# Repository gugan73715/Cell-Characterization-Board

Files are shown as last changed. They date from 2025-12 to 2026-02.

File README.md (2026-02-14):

# Cell Characterization Board V1.2
This project is a 10-channel sequential lithium-ion cell (18650) characterization instrument designed to measure cell voltage, discharge current, internal resistance, and capacity under a controlled constant-current load of up to 5 A. The Cell data would be displayed on an LCD and stored on a MicroSD card which can be used to plot discharge curves using Excel/Matlab/Python. Protection features include Reverse Polarity Protection for each channel, Low voltage cut-off and hardware controlled sequential switching circuit with hardware interlock to create mutually exclusive channels.

V1.2 serves as a validation vehicle for the custom analog front-end and discharge bus, utilizing a modular MCU architecture (Nucleo/Nano) to minimize BOM and assembly costs as well as accelerate testing. Planned V2 would be an integrated STM32G0B1CCT6 based revision with a SPI TFT display.

## Primary Use Case

This system is designed to characterize and screen individual lithium-ion cells prior to adding it into a battery pack for UBC Rocket's Cloudburst rocket. This allows to exclude defective, mismatched, or degraded cells before battery pack assembly. It also helps prevent cell imbalance in series strings, individual cells overheating during discharge and reduced pack capacity due to lower cell capacity. This device could also be used in other projects involving high-energy battery systems such as Student Formula SAE electric vehicles, solar car teams, and any project requiring testing and characterization of large numbers of lithium-ion cells prior to pack assembly. 

## Key design goals
- Programmable constant-current discharge
- Accurate, ratiometric voltage and current measurement
- Fault-tolerant handling of reverse polarity and missing cells
- Sequential testing to minimize BOM cost and thermal complexity
- Hardware based protection features for reliability
- Reduce manufacturing and assembly cost as much as possible due to budget constraint
- Rapid bring up
- Clear documentation of design intent and constraints
  
# PCB Design:
## Latest 3D Render:
Cell Characterization Board V1 2 3D Render - Top
Cell Characterization Board V1 2 3D Render - Bottom
## V1.2:


## System Validation & Discharge Data:
CELL ID 3
Full discharge curve of a Sony VTC4 cell generated using the cell data from V1.2 10-channel tester, ploted using MATLAB. The system maintained a stable 1.5A constant current discharge, yielding a capacity measurement that matched the manufacturer's datasheet within 5% and a DCIR of 33mohm. This data confirms the precision of the op-amp control loop over a full discharge cycle and MOSFET maintained a approximate 45-50C temperature.

## Overview:
The system is implemented on a custom 4-layer mixed-signal PCB (SIG / GND / PWR / SIG) optimized for high-current power handling, precision analog measurement and noise handling. GND and PWR plane are continuous and unbroken providing low-impedance return paths and a stable reference plane. Proper zoning (Analog/Digital/Power) based component placement for noise immunity and short traces. Cell holders and relays are placed on both sides to decrease PCB size which helps reduce PCB manufacturing cost.
### High-Current Routing
- All >2 A paths use wide copper pours with stitching vias if possible to distribute the current
- All high current paths are kept as far away as possible from sensitive analog traces

### Analog Integrity
- All analog traces are on top layer with a GND plane below them
- Analog traces are kept as short as possible
- Important analog signals are buffered and have a decoupling capacitor close to it
- Quasi-Kelvin sense (Separate PWR and SIG traces but shared GND) is used for current and voltage measurement
  
### Noise and Protection
- Relay drive and switching currents are physically separated from the analog front-end
- External flyback diodes placed adjacent to each relay
- Relay coil and Flyback traces are kept as short as possible and fanned out to prevent noise from adjacent traces
- Decoupling capacitors placed close to each IC supply pin
- Reverse polarity protection for each channel using P-channel MOSFETs
- V_Cell traces are connected straight to cell holder for Quasi-kelvin sense and current limiting resistor on each trace to protect the MUX in case of reverse polarity.
- NTC on Load MOSFET's heatsink for active over temperature protection
- 30 ms Soft start for BUCK IC to prevent overshoot and inrush current

### Debugging
- Testpoints for 5V, 3.3V, 2.5V ref, GND, I_set, Constant Current op-amp feedback line, MOSFET Gate and I_sense.
- External UART, SPI and I2C headers for logic analysis
- MUX-out(Cell voltage) is accessible through MCU header

### Assembly & Cost Optimization
- 5 channels were placed on top and bottom to reduce PCB size and save fabrication costs
- Passive components are assembled by fabrication house and all of them have been placed on top for one sided assembly
- Active ICs, cell holders and connectors are hand-assembled post-fabrication to reduce assembly cost while retaining full control over critical components

# Hardware
08e247f1-ca4d-435c-84c2-786f73447f0c-0

## System Architecture Summary (Click subsection header for schematic sheet)
<details>
<summary><h3>Buck and LDO</h3></summary>
  
Buck and LDO Schematic (https://github.com/user-attachments/assets/7cbbd1c2-d676-4704-b09d-97c5c336276e)
</details>

- input DC Jack / XT60: 8–40 V
- input USB-C: 5V 3A (Non-PD)
- 5 V logic rail via AP64502QSP-13 based synchronous buck converter
- Dedicated 3.3 V LDO for MicroSD and SPI

<details>
<summary><h3>Constant Current Sink</h3></summary>
  
Constant Current Sink (https://github.com/user-attachments/assets/1adb6a28-354b-4ce8-b8a3-19815ae03084)
</details>

- IRLZ44N Logic level MOSFET and TLV9162 control op-amp
- Low side 50mohm 3W shunt
- DAC60501ZDGSR 12-bit DAC for precise control of discharge current and controlled via I2C
- Internal 2.5 V precision reference of DAC is shared by ADC as well
- Amplified I_sense signal (0 - 2.5V) using MCP6001 for better resolution
- Theoretical MOSFET temperature with heat sink (θ_normal = 2.6 C/W) at max case (5A) is 115.86 C (Assuming 25 C ambient)
- Load MOSFET temperature monitoring via NTC
- Maximum discharge current: 5 A

<details>
<summary><h3>MCU</h3></summary>

MCU (https://github.com/user-attachments/assets/76e0b13c-49a7-4943-83e6-0d6fc5a95909)

</details>

- Compatible with 3.3V STM32 Nucleo boards with nano connectivity like NUCLEO-L432KC and Arduino nano
- External I2C header for debugging and future expansion modules
- External UART header for telemetry

<details>
<summary><h3>Cell Holder</h3></summary>

Cell Holder (https://github.com/user-attachments/assets/d6683df6-3a02-4f7b-97c8-28835414f6b9)

</details>

- DIY 3D printed SMD 18650 cell holders (similar to Keystone 1043) with 0.2mm nickel strips as cell contacts to save BOM cost
- Reverse polarity protection for each channel using MCQ7328-TP P-channel MOSFETs
- Cell voltage sense traces are connected straight to cell holder pads for quasi-kelvin sense

<details>
<summary><h3>Sequential Cell Switching</h3></summary>

Sequential Cell Switching (https://github.com/user-attachments/assets/236b81a5-ea0e-4242-863e-f045defb3f62)

</details>

- Control Logic: MCU -> I2C Expander -> Line Decoder (For mutually exclusive channels) -> Relay Driver -> Relay -> Cell Holder
- Relay-based physical isolation of cells driven by darlington transistor array on low side
- PCF8575PWR I2C expander for I/O expansion
- CD4514BM96 decoder to prevent connecting more than one channel at the same time and an active high inhibit pin controlled by I2C expander
- External pull ups on all I2C lines and external flyback diodes on all relays

<details>
<summary><h3>Cell Monitoring</h3></summary>

Cell Monitoring (https://github.com/user-attachments/assets/edf4d94d-06c7-463c-b50f-4eb45057faaf)

</details>

- CD74HC4067SM96 16:1 analog MUX for cell voltage sampling
- MUX out is converted to a signal of 0 to 2.5V using a voltage divider and then buffered
- Current limiting resistor(limits to 2.1mA) on each channel to protect the MUX in case of reverse polarity (MUX's internal ESD clamp diode forward biases)

<details>
<summary><h3>MicroSD</h3></summary>

MicroSD (https://github.com/user-attachments/assets/2866bfb3-0861-4d20-aa4e-4b10ece4d7fd)

</details>

- Data is written to MicroSD using SPI
- TXU0304PWR unidirectional voltage level translator for 5V to 3.3V for SCK, MOSI, CS (MCU to MicroSD) and 3.3V to 5V for MISO (MicroSD to MCU)
- SD detect LED for user-friendliness
- Parameters: Time, Cell Voltage, Discharge Current, Internal Resistance, I_set, Cut-off voltage and capacity (mAh / Wh)
- Internal Resistance is calculated using r = (V_OC - V_sense)/I. (Voltage drop across cell under a load)

## Prototyping and Validation:

### LTspice simulation: (Constant Current Sink)



### Breadboard prototyping:


- Constant current sink prototype built using IRL510 + LM158J
- Shunt resistor: 1.5 Ω / 5 W
- Gate and feedback resistors as implemented in hardware
- 0.5V out DAC emulated via resistive divider from 5 V
- Load driven by a current-limited (For safety) bench supply (2.5 V–4.2 V sweep)

Measured discharge current remained approximately constant (~340 mA) across the full input voltage range.

# Firmware

- Initial firmware developed using Arduino IDE for rapid bring-up
- Secondary firmware under development using STM32CubeIDE with STM32HAL and testing using an NUCLEO-G431KB

### Objectives:

- Validation of the sequential switching mechanism to guarantee mutual exclusivity of active channels
- Cell voltage sampling verification across all channels using the MUX
- Verify ADC and DAC resolution using the shared 2.5 V reference
- Validation of current measurement accuracy and stability across the full discharge range

# Planned Revision (V2):

- Transitioning to a STM32G0B1CCT6 onboard MCU
- Switching to SPI-based TFT display for real-time visualization
- Switching to Zero-drift, ultra-low-offset op-amp for better accuracy
- NTC on each channel for cell temperature monitoring
- Short-circuit and overtemperature protection for each channel 
- Firmware detection of protection features and informing the user
- Audible and visual fault and status indication (buzzer and status LEDs)

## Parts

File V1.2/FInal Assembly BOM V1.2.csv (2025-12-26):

Description | Designator | Footprint | JLCPCB Part #
Chip Capacitor, 100 nF, +/- 10%, 50 V, 0805 (2012 Metric) | C1, C2, C3, C4, C12, C14, C15, C16, C17, C18, C19, C20, C23, C24, C25 | CAPC2013X95X50LL10T25 | C28233
Chip Multilayer Ceramic Capacitors for General Purpose, 1206, 47uF, X5R, 15%, 20%, 10V | C5, C6, C7, C8, C9 | FP-GRM31C-0_2-e0_3_0_8-IPC_C | C76659
CAP CER 10UF 50V X5R 1206 | C10, C11 | FP-CL31-IPC_C | C1710
Ceramic Capacitor for Automotive 10nF ±10% 100VDC X8R 0805 Paper T/R | C13 | FP-GCM219-0_15-IPC_C | C1848
Chip Capacitor, 1 uF, +/- 10%, 25 V, -55 to 125 degC, 1206 (3216 Metric), RoHS, Tape and Reel | C21, C22 | CAPC3216X180X50ML20T25 | C1848
Surface Mount Glass Passivated Rectifier, 1000V, 1 A, -65 to 125 degC, 2-Pin SMA Package, RoHS, Tape and Reel | D1, D2, D3, D4, D5, D6, D7, D8, D9, D10 | DIOD-S1M-13-F-SMA-2_V | C95872
LED Yellow, 75 mW, 80 mA, -55 to 85 degC, 2-Pin SMD, RoHS, Tape and Reel | D11 | LTST-C170KSKT_V | C2296
Chip Ferrite Bead Array, 1206, 120O @ 100MHz, 0.02O, 25%, 3.5A | FB1 | FP-BLM31-0_2-t1_1-MFG | C85841
Chip Resistor, 10 KOhm, +/- 1%, 125 mW, -55 to 155 degC, 0805 (2012 Metric) | R1, R11 | RESC2013X50X35ML15T15 | C17414
1.5kO ±5% 0.125W 0805 Thick Film Chip Resistor AEC-Q200 compliant | R2 | FP-RMCF0805-IPC_B | C4310
RES SMD 100 OHM 1% 1/8W 0603 | R3, R4 | FP-MCT0603-IPC_B | C23186
Chip Resistor, 4.7 KOhm, +/- 1%, 0.125 W, -55 to 155 degC, 0805 (2012 Metric) | R5, R8, R21, RPU1, RPU2, RPU3, RPU4, RPU5, RPU6, RPU7, RPU8 | RESC2013X70X40ML20T20 | C17673
RES 1.05K OHM 0.5% 1/5W 0805 | R6 | FP-MCU0805-IPC_C | C17695
220O ±5% 0.125W 0805 Thick Film Chip Resistor AEC-Q200 compliant | R7 | FP-RMCF0805-IPC_A | C17557
8K2 0.125W 1% 0805 (2012 Metric) SMD | R9 | RESC0805(2012)_N | C17828
RES Thick Film, 7.5kO, 1%, 0.5W, 100ppm/°C, 0805 | R10 | FP-CRCW0805-HPe3-IPC_B | C17807
RES 10kO 5.00% 0.2W 0603 | R12, R22, R23, R24, R25, R26, R27, R28, R29, R30, R31 | FP-AC0603-IPC_A | C25804
Thick Film Chip Resistors 0805 300O 0.125W 1% 100ppm/°C | R13, R19 | FP-CR0805-MFG | C17617
CRGP0805 18KO 0.33W ±100ppm/°C 1% 150V | R14, R16 | FP-CRGP0805-IPC_C | C17506
1kO ±0.1% 0.125W, 1/8W Chip Resistor 0805 (2012 Metric) Moisture Resistant Thin Film | R15 | FP-RN73R2A-IPC_A | C17513
RES 1.05K OHM 0.5% 1/5W 0805 | R17, R18 | FP-MCU0805-IPC_A | C17604
RES Thick Film, 200kO, 1%, 0.33W, 100ppm/°C, 0603 | R20 | FP-CRCW0603-HPe3-MFG | C17617
RES Thin Film, 2kO, 0.1%, 0.1W, 25ppm/°C, 0603 | R32, R33, R34, R35, R36, R37, R38, R39, R40, R41 | FP-TFCR0603-IPC_B | C22975
CRGCQ 0603 1K2 1% | R42 | FP-CRGCQ0603-IPC_C | C22765
CRGCQ 0603 2K2 1% | R43 | FP-CRGCQ0603-IPC_C | C4190
RES 0.05 OHM 1% 3W 2512 | SHUNT | FP-CRA2512-IPC_A | C160588
SWITCH TACTILE SPST-NO 0.05A 24V | START_SW, STOP_SW | FP-2-1977223-2-MFG | C963361

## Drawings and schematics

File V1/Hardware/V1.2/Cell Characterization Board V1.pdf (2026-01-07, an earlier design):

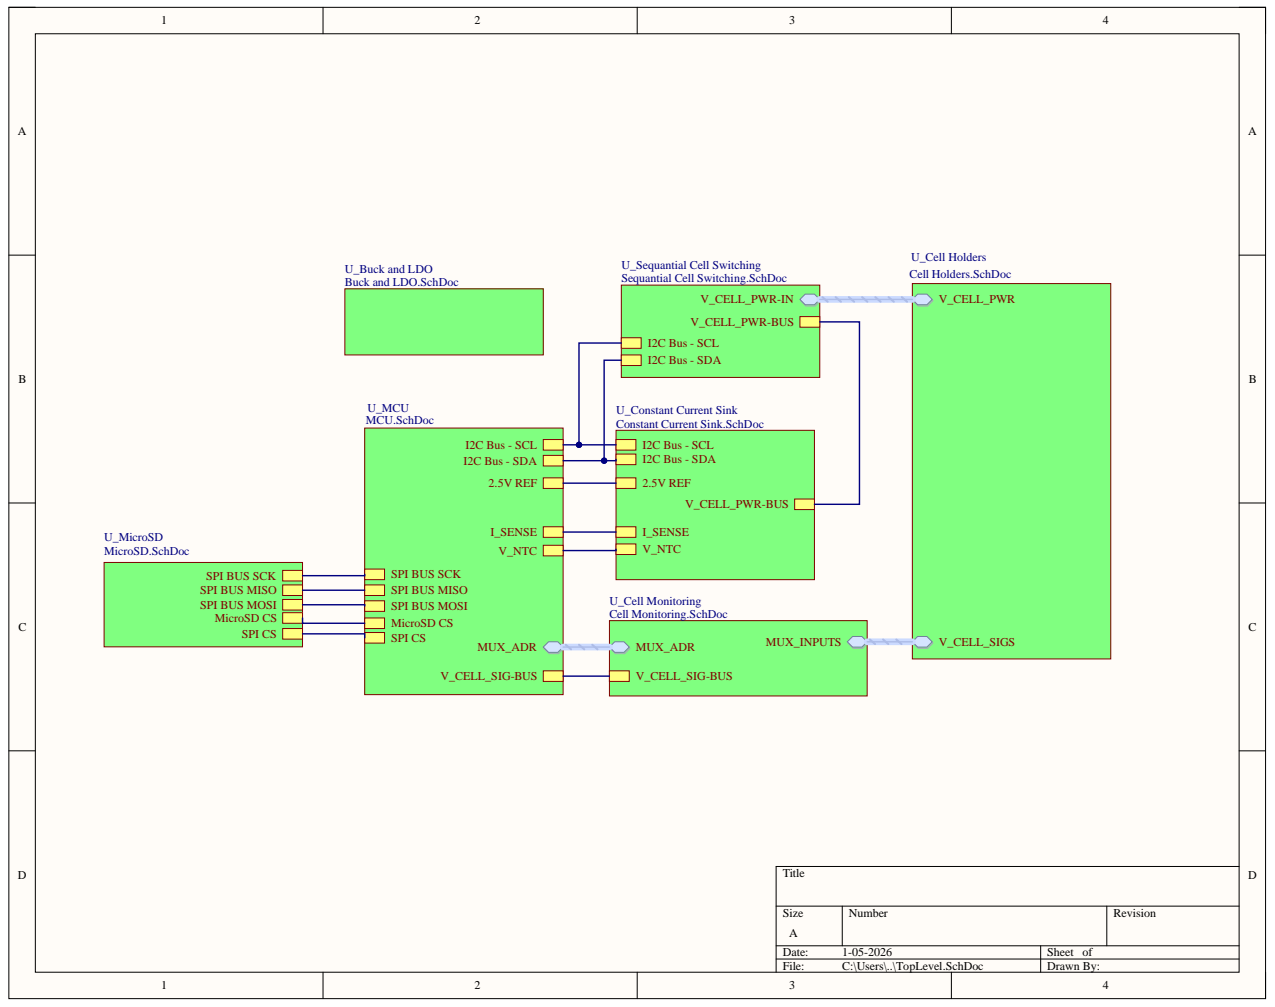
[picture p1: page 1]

U_Sequantial Cell Switching
Sequantial Cell Switching.SchDoc

U_Buck and LDO
Buck and LDO.SchDoc

U_Constant Current Sink
Constant Current Sink.SchDoc

Size A | Number | Revision

Date: 1-05-2026 | Sheet of
File: C:\Users\..\TopLevel.SchDoc | Drawn By:

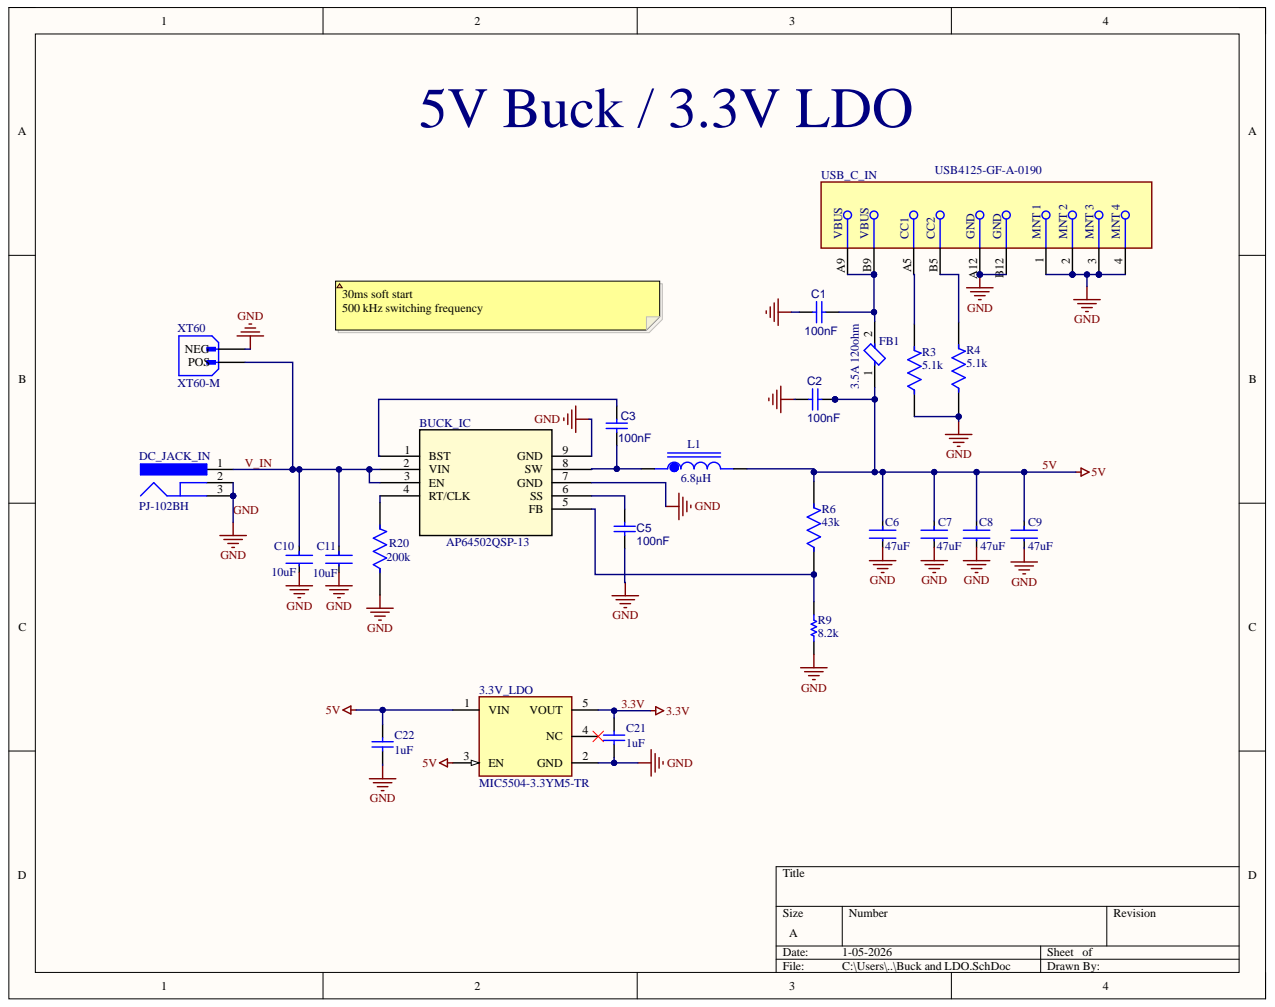
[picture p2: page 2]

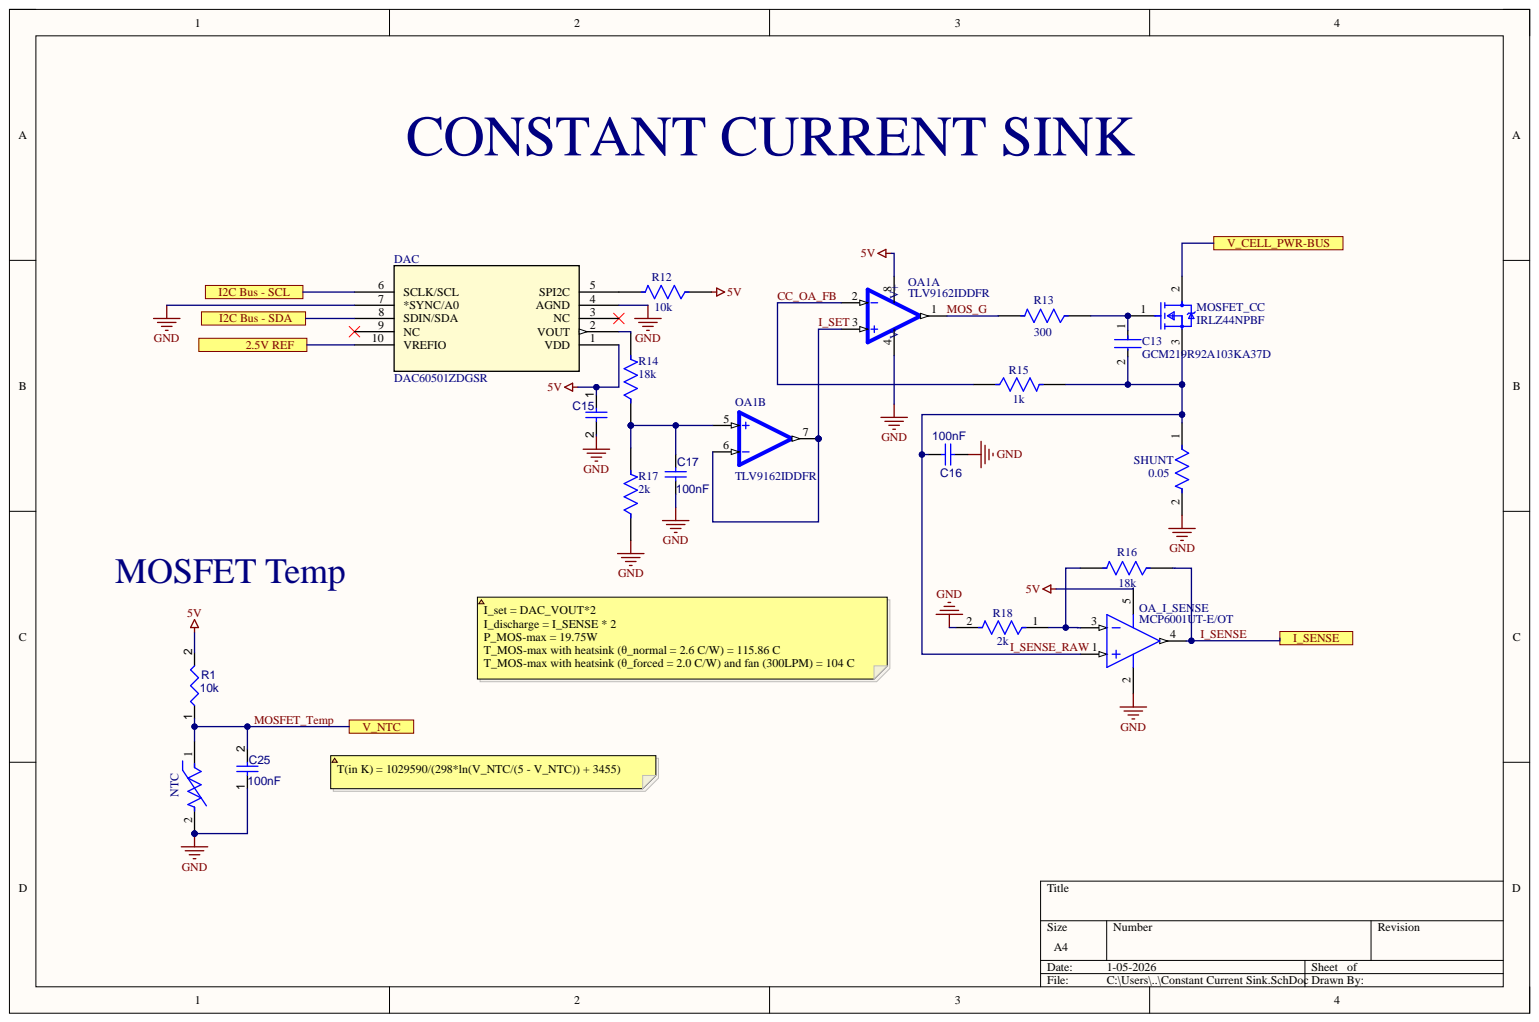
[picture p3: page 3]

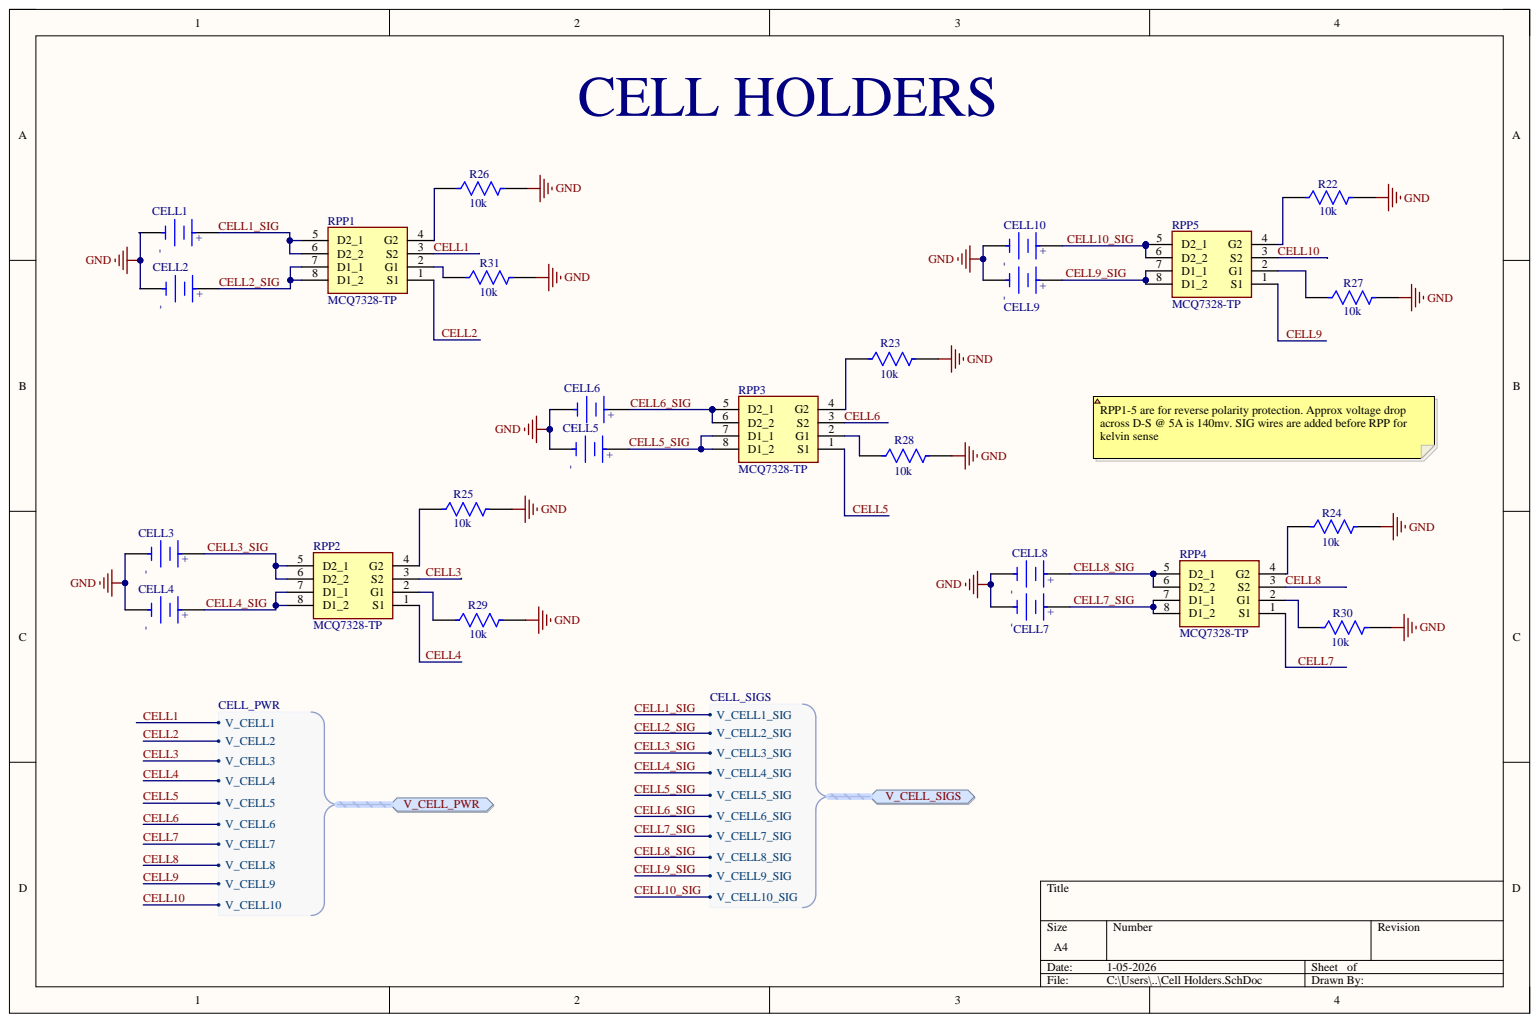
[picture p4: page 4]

RPP1-5 are for reverse polarity protection. Approx voltage drop
across D-S @ 5A is 140mv. SIG wires are added before RPP for
kelvin sense

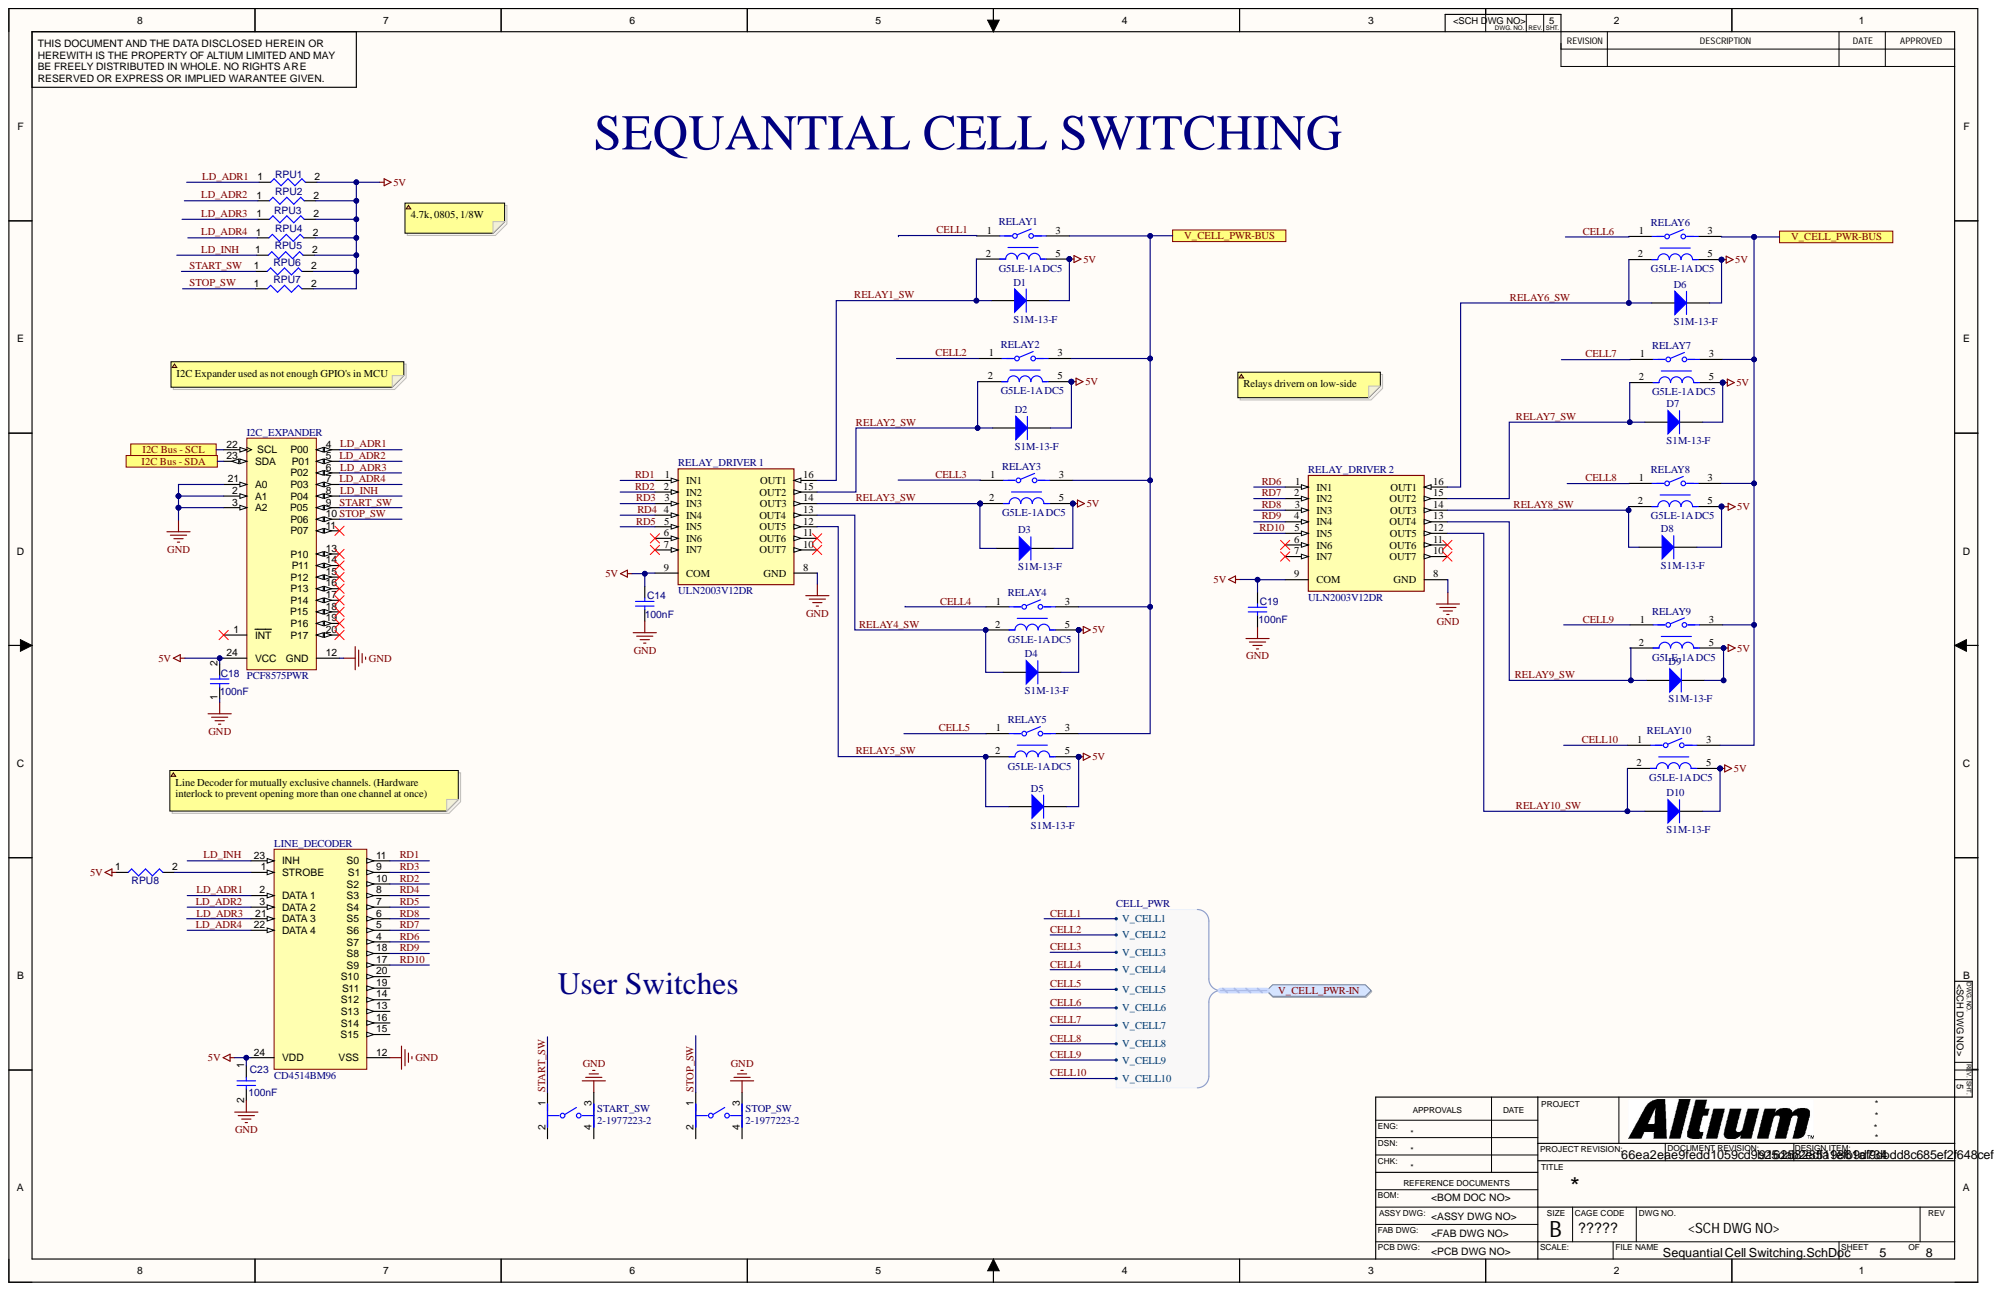
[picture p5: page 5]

DWG. NO. | REV. | SHT. <SCH DWG NO> 5

THIS DOCUMENT AND THE DATA DISCLOSED HEREIN OR HEREWITH IS THE PROPERTY OF ALTIUM LIMITED AND MAY BE FREELY DISTRIBUTED IN WHOLE. NO RIGHTS ARE RESERVED OR EXPRESS OR IMPLIED WARANTEE GIVEN. | | REVISION | DESCRIPTION | DATE | APPROVED

I2C Expander used as not enough GPIO's in MCU

Relays drivern on low-side

Line Decoder for mutually exclusive channels. (Hardware
interlock to prevent opening more than one channel at once)

REV. SHT. DWG. NO.

DATE | PROJECT | * * APPROVALS * *

ENG: *
CHK: * | | TITLE *

DSN: *

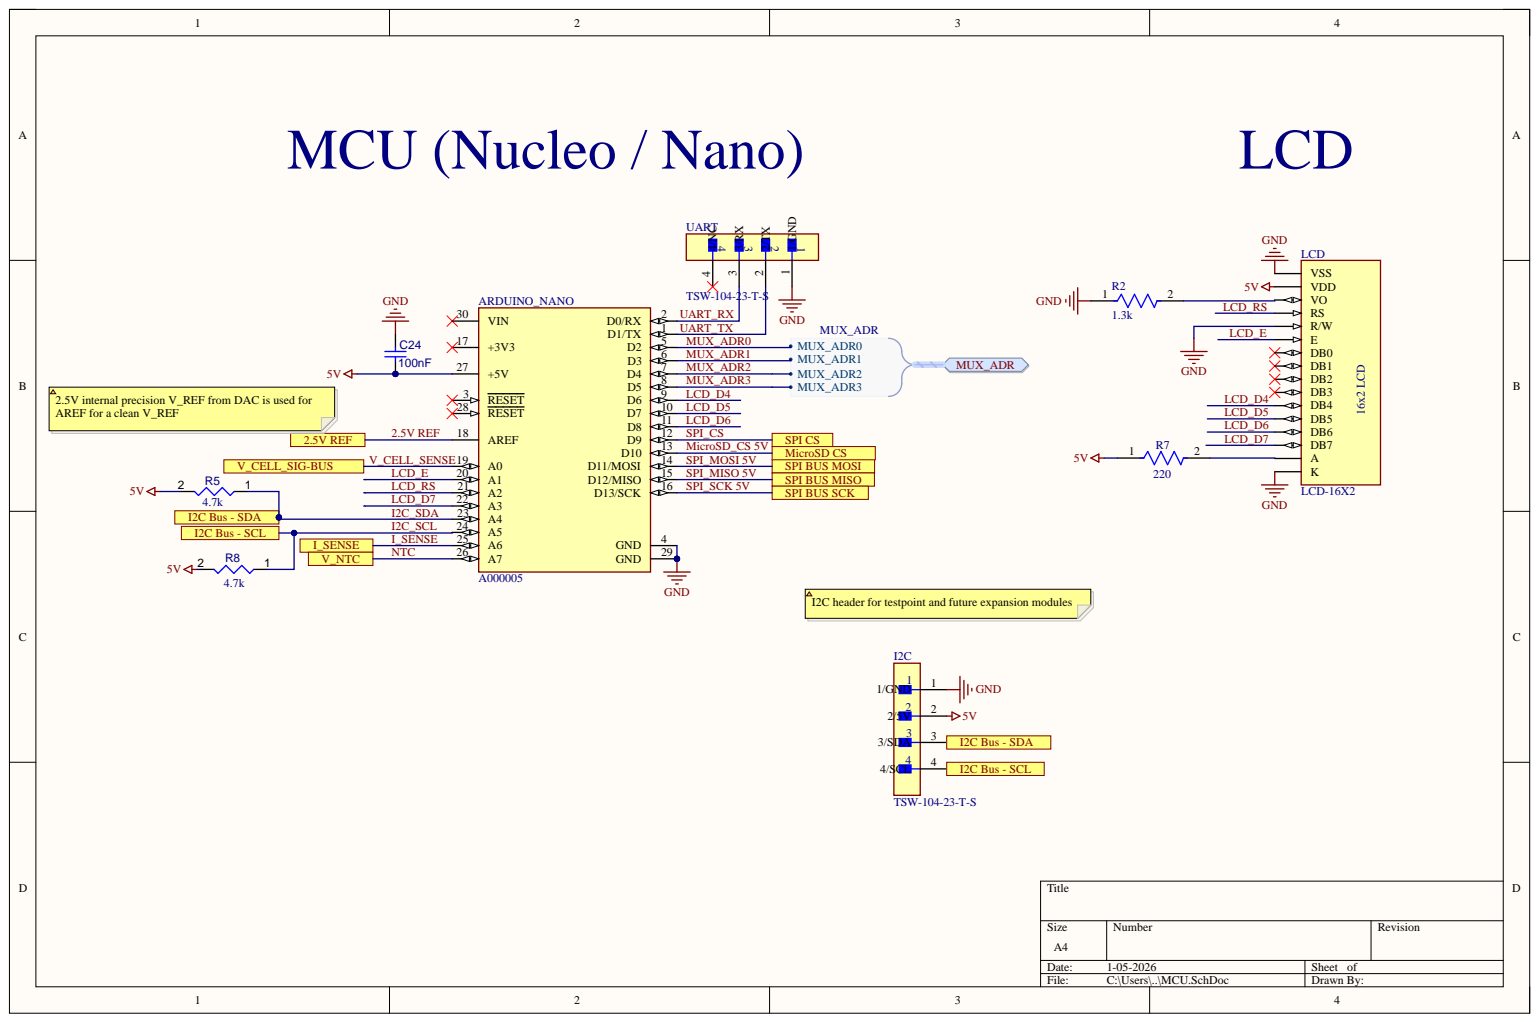
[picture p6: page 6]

TSW-104-23-T-S UART_RX

LCD_E

2.5V internal precision V_REF from DAC is used for
AREF for a clean V_REF

I2C header for testpoint and future expansion modules

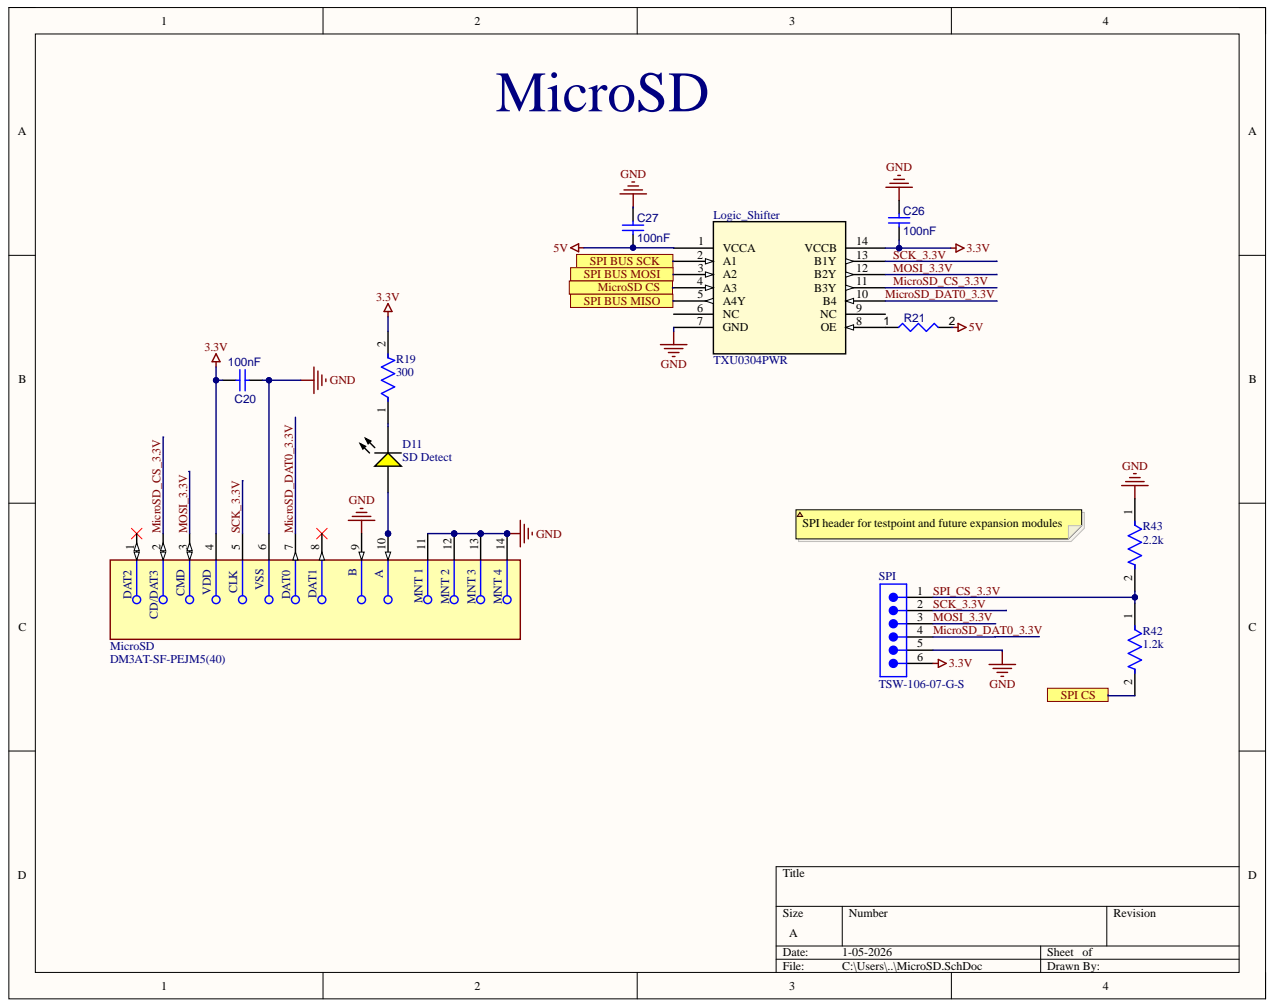
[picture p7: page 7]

SPI header for testpoint and future expansion modules

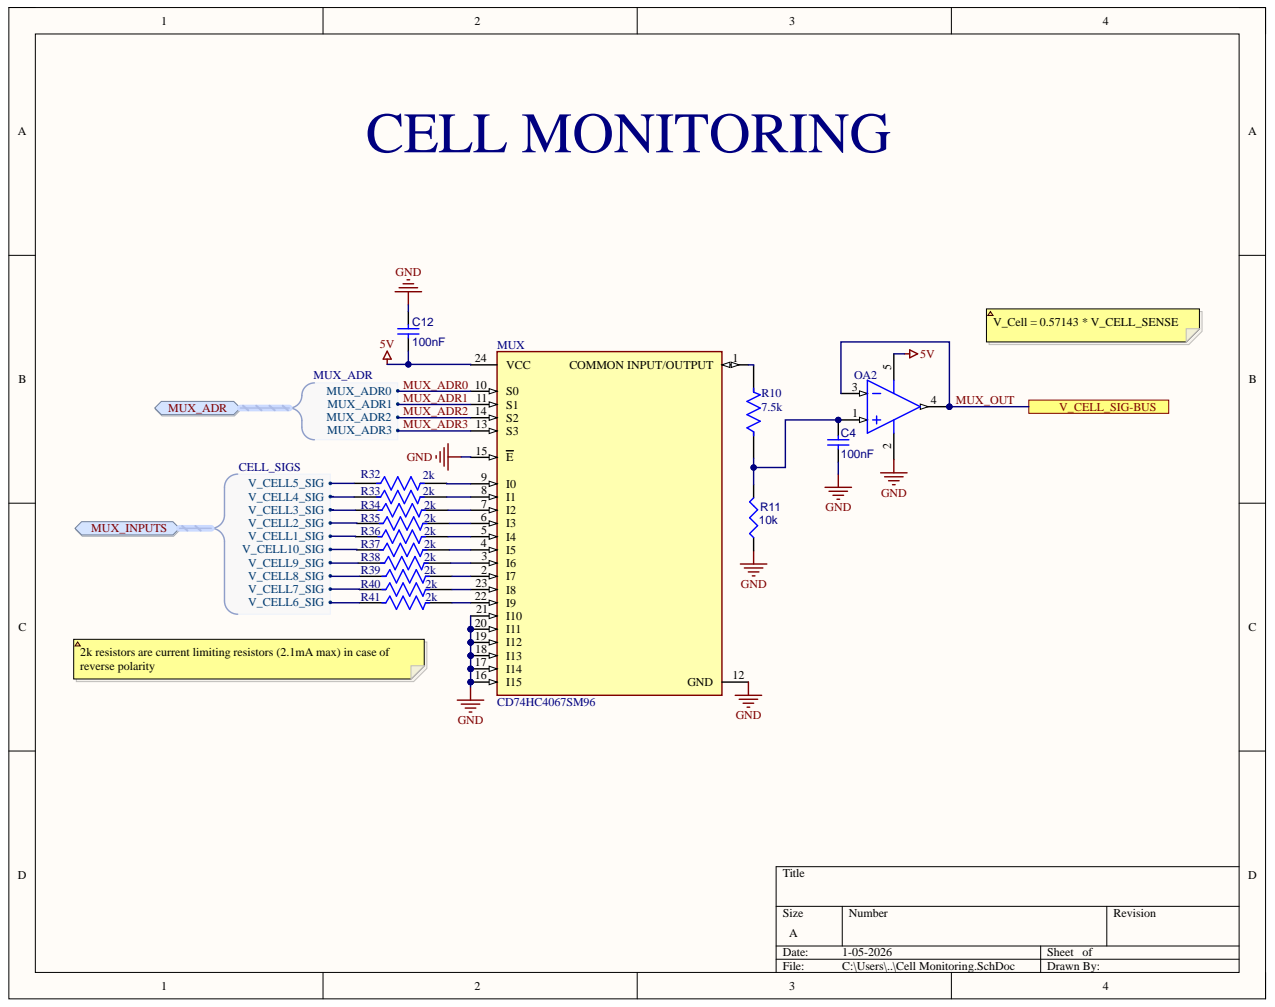
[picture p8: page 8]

2k resistors are current limiting resistors (2.1mA max) in case of
reverse polarity

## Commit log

2025-12-26 V1.1 and V1.2
    [DC Battery Capacity Tester V1.PrjPcb, DC Battery tester.SchDoc, FInal Assembly BOM V1.2.csv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]
2026-01-01 Fixed the V1.2 Assembly BOM and intial commit for firmware (auto)
    [Cell Characterization Board V1.PrjPcb]
2026-01-05 Added 3D Renders and fixed DRC errors
    [Cell Characterization Board V1.PrjPcb]
2026-01-07 Final Deliverables
    [Buck and LDO.SchDoc, Cell Characterization Board V1.PrjPcb, Cell Holders.SchDoc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]
